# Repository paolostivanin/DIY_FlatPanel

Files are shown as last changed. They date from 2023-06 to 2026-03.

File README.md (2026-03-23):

# DIY Flat Panel

A DIY PC-controlled flat panel for astrophotography calibration frames, using the [Alnitak](http://www.optecinc.com/astronomy/catalog/alnitak/flip-flat.htm) (Flip-Flat/Flat-Man) serial protocol. Compatible with NINA, SGP, and other capture software that supports Alnitak devices.

## How It Works

An Arduino Nano drives an A4 LED light pad via PWM through an IRF520N MOSFET, allowing software to control brightness (0-255) over a serial connection at 9600 baud.

## Hardware

### Components
- Arduino Nano
- IRF520N N-channel MOSFET
- A4 LED light pad (see [tested panels](#tested-flat-panels) below)

### Circuit

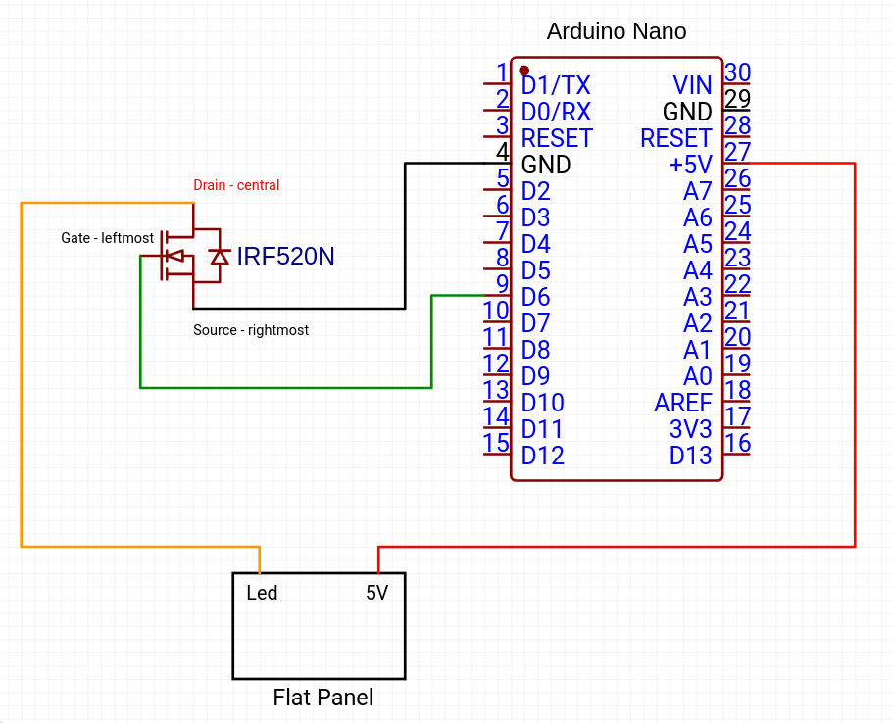
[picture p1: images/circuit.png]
Circuit diagram


- **D6** (PWM) connects to the MOSFET gate to control LED brightness
- The MOSFET switches the flat panel's LED line, with the panel powered from its own 5V supply
- The Arduino is powered via USB

### 3D Printed Parts

The `src/openscad/` directory contains two printable parts:

- **flatpanel.scad** - Panel cover with a center hole for the telescope (95mm diameter) and mounting feet. Sized for an A4 light pad (340x240mm usable area).
- **arducover.scad** - Enclosure for the Arduino Nano with an integrated USB cable clip.

Open in [OpenSCAD](https://openscad.org/) to preview, then export to STL for printing.

## Firmware

The Arduino firmware (`src/arduino/flatpanel.ino`) implements the Alnitak command protocol. Open in Arduino IDE and upload — no external libraries required.

## Tested Flat Panels

Uniformity tested using [John Upton's method](docs/test_flat_panel.md).

| Panel | Purchased | Status | Uniformity |
|---|---|---|---|
| [NXDRS A4](https://www.amazon.it/gp/product/B07GPRGKPY) | Sep 2020 | Died Nov 2023 | 1.6% |
| [Omasi A4](https://www.amazon.it/gp/product/B089LPMDDS) | Nov 2023 | Active | 0.59% |

## Changelog

- **1.0** - Initial revision
- **1.1** - Panel height increased by 1mm (2mm to 3mm); arducover made smaller
- **1.2** - Added bigger feet and middle feet on the long sides

## Credits

- https://www.blackwaterskies.co.uk/2020/03/cheap-diy-remote-controlled-flat-panel/
- https://github.com/red-man/Alnitak-Lightbox-Clone/
- https://gist.github.com/ednisley/52b8a6303fa130fe38858488b978874b

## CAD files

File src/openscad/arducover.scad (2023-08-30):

// Revision 1.1 (2023-Aug-30)

// Case
difference() {
    cube([90, 54, 17]);
    #translate([0, 2])cube([90, 50, 15]);
}


// Back
difference(){
    difference(){
        #translate([70, 0])cube([20, 54, 17]);
        #translate([70, 2])cube([18, 50, 15]);
    }
    #translate([88, 20])cube([2, 10, 3]);
}


// Front
difference(){
    difference(){
        #translate([0, 0])cube([20, 54, 17]);
        #translate([2, 2])cube([18, 50, 15]);
    }
    #translate([0, 20])cube([2, 25, 10]);
}


// This is for holding the cable, so that I don't have to disconnect the USB every time. The cable diameter is 3.45mm
ThreadThick = 0.25;
ThreadWidth = 0.40;
HoleWindage = 0.2;			// extra clearance
Protrusion = 0.1;			// make holes end cleanly

function IntegerMultiple(Size,Unit) = Unit * ceil(Size / Unit);

CableOD = 3.5;                              // cable jacket

Base = [4*CableOD,4*CableOD,3*ThreadThick];	  // overall base and slab thickness
CornerRadius = CableOD/2;                   // radius of square corners
CornerSides = 4*4;                          // total sides on square corner cylinders
NumSides = 6*3;                             // total sides for cylindrical base

module CableClip() {
    intersection() {
        resize(Base + [0,0,2*(Base[2] + CableOD)])
        sphere(d=Base[0],$fn=NumSides);

        union() {
            translate([0,0,Base[2]/2])
            cube(Base,center=true);

            for (j=[-1,1]) {
                translate([0,j*(Base[1]/2 - 0.125*(Base[1] - CableOD)/2),(Base[2] - Protrusion)])
                    resize([Base[0]/0.75,0,0])
                        cylinder(d1=0.75*(Base[1]-CableOD),
                        d2=(Base[1]-CableOD)/cos(0*180/NumSides),
                        h=(CableOD + Protrusion),
                        center=false,$fn=NumSides);
            }
        }
    }

//    color("Green",0.2)
//    translate([0,0,Base[2] + CableOD/2])
//    rotate([0,90,0])
//    cylinder(d=CableOD,h=2*Base[0],center=true,$fn=48);
}

#translate([30, 54, 8])rotate([270, 0, 0])CableClip();

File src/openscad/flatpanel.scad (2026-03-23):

// Revision 1.2 (2026-Mar-23)
// The panel is 359mm x 269mm. There is a black frame of 20mm, so we can reduce the cover size.
panel_width = 340;
panel_depth = 240;
// The panel is 3mm high, the foot are 4mm hight. Total height 7mm.
panel_height = 5;
scope_diameter = 95;
foot_height = 4;
foot_width = 12;
foot_depth = 40;
module feet() {
    cube([foot_width, foot_depth, foot_height]);
}
difference() {
    cube([panel_width, panel_depth, panel_height]);
    #translate([panel_width/2, panel_depth/2])cylinder(panel_height, scope_diameter, scope_diameter);
}
// Corner feet
#translate([0, 0, panel_height])feet();
#translate([panel_width-foot_width, 0, panel_height])feet();
#translate([0, panel_depth-foot_depth, panel_height])feet();
#translate([panel_width-foot_width, panel_depth-foot_depth, panel_height])feet();
// Middle feet on long sides (rotated 90°)
#translate([panel_width/2-foot_depth/2, 0, panel_height])cube([foot_depth, foot_width, foot_height]);
#translate([panel_width/2-foot_depth/2, panel_depth-foot_width, panel_height])cube([foot_depth, foot_width, foot_height]);

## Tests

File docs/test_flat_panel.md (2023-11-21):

From [this](https://www.astrobin.com/forum/c/astrophotography/equipment/flat-panel-for-the-zwo-asi294mm-pro/?page=1) Astrobin thread:

* Set up telescope and camera as when taking flat frames.
* Shoot 10 flat frames with similar median brightness at about 30,000 ADU (`set #1`).
* Rotate the flat light source by 90° leaving the camera and telescope in the same position.
* Shoot 10 more flat frames with similar median brightness at about 30,000 ADU (`set #2`).
* In PixInsight, integrate `set #1` using Image_Integration as you would for creating a Master Flat.
* Name the `set #1` integrated result `Flat_00_Deg`.
* In PixInsight, integrate `set #2` using Image_Integration as you would for creating a Master Flat.
* Name the `set #2` integrated result `Flat_90_Deg`.
* Use Pixel Math to divide one integrated result by the other and normalize it: `Flat_00_Deg / Flat_90_Deg / 2.0`
  Be sure to select Create New Image and select the output Sample Format to be 32 bit Floating Point.
* Name this new image `Flat_Diff`.
* Run the Flat Contour Plot script on the Flat_Diff frame. Select the script parameters as: `50, 2.5, 15, 50`
* On the resulting contour plot, note the numbers shown at the top (Max) and bottom (Min) along the right side.
* Calculate the total non-uniformity in the Flat as: `total_non-uniformity = (Max - Min) / ((Max + Min) / 2)`
* You can optionally divide this by 2 to get the ± deviation from the mean value.

For general astrophotography, if your number is 5% or less, you are pretty good. If it is 2% or less, you are about optimum for "pretty picture" photography. If it is less that 1%, you have an excellent flat light source. If your value is less than 0.5%, then your system is about as good as it can be and you should be able to perform high precision photometric measurements of star magnitudes into the range of 0.01 magnitude.

If your source is significantly worse than 5%, then add a layer or two of additional diffusing material and try again. As an alternative, you can use the method John Tucker uses and take multiple flat frames rotating the light source slightly between each and then stacking them.

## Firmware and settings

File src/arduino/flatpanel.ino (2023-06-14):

/*
What: LEDLightBoxAlnitak - PC controlled lightbox implmented using the 
  Alnitak (Flip-Flat/Flat-Man) command set found here:
  http://www.optecinc.com/astronomy/pdf/Alnitak%20Astrosystems%20GenericCommandsR3.pdf

Who: 
  Created By: Jared Wellman - jared@mainsequencesoftware.com
  Updated By: red-man

Changelog:

2020-06-25
  Updated to align with spec in link above.  Previously it was appending '000\n' instead
  of 'OOO\r' to the responses and did not work with NINA.


Typical usage on the command prompt:
Send     : >SOOO\n      //request state
Recieve  : *S19OOO\n    //returned state

Send     : >B128\n      //set brightness 128
Recieve  : *B19128\n    //confirming brightness set to 128

Send     : >JOOO\n      //get brightness
Recieve  : *B19128\n    //brightness value of 128 (assuming as set from above)

Send     : >LOOO\n      //turn light on (uses set brightness value)
Recieve  : *L19OOO\n    //confirms light turned on

Send     : >DOOO\n      //turn light off (brightness value should not be changed)
Recieve  : *D19OOO\n    //confirms light turned off.
*/

volatile int ledPin = 6;      // the pin that the LED is attached to, needs to be a PWM pin.
int brightness = 0;

enum devices
{
  FLAT_MAN_L = 10,
  FLAT_MAN_XL = 15,
  FLAT_MAN = 19,
  FLIP_FLAT = 99
};

enum motorStatuses
{
  STOPPED = 0,
  RUNNING
};

enum lightStatuses
{
  OFF = 0,
  ON
};

enum shutterStatuses
{
  UNKNOWN = 0, // ie not open or closed...could be moving
  CLOSED,
  OPEN
};


int deviceId = FLAT_MAN;
int motorStatus = STOPPED;
int lightStatus = OFF;
int coverStatus = UNKNOWN;

void setup()
{
  // initialize the serial communication:
  Serial.begin(9600);
  //Serial.begin(115200);
  // initialize the ledPin as an output:
  pinMode(ledPin, OUTPUT);
  analogWrite(ledPin, 0);
}

void loop() 
{
  handleSerial();
}


void handleSerial()
{
  if( Serial.available() >= 6 )  // all incoming communications are fixed length at 6 bytes including the \n
  {
    char* cmd;
  char* data;
    char temp[10];
    
    int len = 0;

    char str[20];
    memset(str, 0, 20);
    
  // I don't personally like using the \r as a command character for reading.  
  // but that's how the command set is.
    Serial.readBytesUntil('\r', str, 20);

  cmd = str + 1;
  data = str + 2;
  
  // useful for debugging to make sure your commands came through and are parsed correctly.
    if( false )
    {
      sprintf( temp, "cmd = >%c%s;\n", cmd, data);
      Serial.print(temp);
    } 
    


    switch( *cmd )
    {
    /*
    Ping device
      Request: >POOO\n
      Return : *PiiOOO\n
        id = deviceId
    */
      case 'P':
      sprintf(temp, "*P%dOOO\n", deviceId);
      Serial.print(temp);
      break;

      /*
    Open shutter
      Request: >OOOO\n
      Return : *OiiOOO\n
        id = deviceId

      This command is only supported on the Flip-Flat!
    */
      case 'O':
      sprintf(temp, "*O%dOOO\n", deviceId);
      SetShutter(OPEN);
      Serial.print(temp);
      break;


      /*
    Close shutter
      Request: >COOO\n
      Return : *CiiOOO\n
        id = deviceId

      This command is only supported on the Flip-Flat!
    */
      case 'C':
      sprintf(temp, "*C%dOOO\n", deviceId);
      SetShutter(CLOSED);
      Serial.print(temp);
      break;

    /*
    Turn light on
      Request: >LOOO\n
      Return : *LiiOOO\n
        id = deviceId
    */
      case 'L':
      sprintf(temp, "*L%dOOO\n", deviceId);
      Serial.print(temp);
      lightStatus = ON;
      analogWrite(ledPin, brightness);
      break;

    /*
    Turn light off
      Request: >DOOO\n
      Return : *DiiOOO\n
        id = deviceId
    */
      case 'D':
      sprintf(temp, "*D%dOOO\n", deviceId);
      Serial.print(temp);
      lightStatus = OFF;
      analogWrite(ledPin, 0);
      break;

    /*
    Set brightness
      Request: >Bxxx\n
        xxx = brightness value from 000-255
      Return : *Biiyyy\n
        id = deviceId
        yyy = value that brightness was set from 000-255
    */
      case 'B':
      brightness = atoi(data);    
      if( lightStatus == ON ) 
        analogWrite(ledPin, brightness);   
      sprintf( temp, "*B%d%03d\n", deviceId, brightness );
      Serial.print(temp);
        break;

    /*
    Get brightness
      Request: >JOOO\n
      Return : *Jiiyyy\n
        id = deviceId
        yyy = current brightness value from 000-255
    */
      case 'J':
        sprintf( temp, "*J%d%03d\n", deviceId, brightness);
        Serial.print(temp);
        break;
      
    /*
    Get device status:
      Request: >SOOO\n
      Return : *SidMLC\n
        id = deviceId
        M  = motor status( 0 stopped, 1 running)
        L  = light status( 0 off, 1 on)
        C  = Cover Status( 0 moving, 1 closed, 2 open)
    */
      case 'S': 
        sprintf( temp, "*S%d%d%d%d\n",deviceId, motorStatus, lightStatus, coverStatus);
        Serial.print(temp);
        break;

    /*
    Get firmware version
      Request: >VOOO\n
      Return : *Vii001\n
        id = deviceId
    */
      case 'V': // get firmware version
      sprintf(temp, "*V%d001\n", deviceId);
      Serial.print(temp);
      break;
    }    

  while( Serial.available() > 0 )
    Serial.read();

  }
}

void SetShutter(int val)
{
  if( val == OPEN && coverStatus != OPEN )
  {
    coverStatus = OPEN;
    // TODO: Implement code to OPEN the shutter.
  }
  else if( val == CLOSED && coverStatus != CLOSED )
  {
    coverStatus = CLOSED;
    // TODO: Implement code to CLOSE the shutter
  }
  else
  {
    // TODO: Actually handle this case
    coverStatus = val;
  }
  
}

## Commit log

2023-06-15 Add circuit and scad files
    [arducover.scad, flatpanel.scad]
2023-06-16 Update arducover
    [arducover.scad]
2023-08-30 Revision 1.1
    [arducover.scad, flatpanel.scad]
2026-03-23 Increase feet size
    [flatpanel.scad]
